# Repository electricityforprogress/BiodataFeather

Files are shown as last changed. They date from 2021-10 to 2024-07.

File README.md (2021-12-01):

# BiodataFeather
Feather daughter board for the Adafruit ESP32 and Huzzah (and others), allowing BLE and RTPMIDI via wifi.
Still a work in progress, and can provide the framework for anyone to use other Adafruit Feather boards
     Lots of Biodata information on my website electricityforprogress.com
See also the project submission on [Hackaday.io](https://hackaday.io/project/182849-biodata-sonification-v05)

3D Enclosure Model: https://www.tinkercad.com/things/8HZnh0ERNtr-biodata-wifi-snap-enclosure

Menu Modes:

From normal Biodata mode, by pressing the button you will enter into the Menu selection where you can turn the knob to select different menus listed below.  When the desired menu color is illuminated click the button and continue to turn the knob to choose a value.  Click a final time to select the value and return to Biodata Mode.  Selections are saved and reloaded each time you turn on the device.  To 'hard reset' press and hold the button while turning on the device, after the light show the White led will display and the factory default settings are applied (Chromatic Scaling, Channel 1, Bluetooth ON, Wifi OFF).

Red - Note Scaling - Entering this mode will illuminate the Red LED, by turning the knob one of the other LEDs will flash indicating a different Note Scaling. Flashing Red = Chromatic, Orange = Minor, Green = Diatonic Minor, Blue = Major, White = Indian

Orange - MIDI Channel - Entering this mode will illuminate the Orange LED, by turning the knob different combinations of the LEDs are used to display the MIDI Channel in 'Binary'.  MIDI Channel can be configured between 1-16, each of the 5 LEDs are used to display the MIDI channel chosen where 1 = 1xxxx, 2 = x1xxx, 3 = 11xxx, etc. The MIDI Channel can then be saved by pressing the button.  So far, this MIDI selection method has been a big PiTA for users, but it is kinda clever.

Green - Wifi On/Off - This mode turns on and off Wifi, default is off. Control is similar to the Bluetooth mode.  If you have uploaded code with your wifi credentials, you can connect to WiFi MIDI

Blue - Bluetooth On/Off - This mode turns on and off Bluetooth, default is ON.  The Blue LED will illuminate and either the Red LED (indicating off) or White LED (indicating on) can be selected by turning the knob.  Press the button again to save the setting.

White - Battery Level - Entering into this mode will display the battery charge percentage by illuminating the white LED and one of the other colors will flash.  Flashing blue = 100%, green = 80%, Yellow = 50%, Green = 30%

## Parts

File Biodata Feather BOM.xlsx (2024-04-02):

Index | Manufacturer Part Number | Manufacturer Name | Description | Attrition % | Requested Quantity 1 | Pack Quantity 1 | Pack Type 1 | Digi-Key Part Number 1 | Unit Price 1 | Extended Price 1 | Minimum Order Quantity 1 | Image | Product Notes
1 | 1825910-7 | TE Connectivity ALCOSWITCH Switches | SWITCH TACTILE SPST-NO 0.05A 24V |  | 1 | 1 | Bulk | 450-1804-ND | 0.13000 | $0.13 | 1 | http://mm.digikey.com/Volume0/opasdata/d220001/medias/images/609/1825910-7.JPG
2 | FG18X7R1H472KNT06 | TDK Corporation | CAP CER 4700PF 50V X7R RADIAL |  | 1 | 1 | Cut Tape (CT) | 445-173274-1-ND | 0.27000 | $0.27 | 1 | https://mm.digikey.com/Volume0/opasdata/d220001/medias/images/1206/FG18_Type.jpg
3 | CFM14JT10R0 | Stackpole Electronics Inc | RES 10 OHM 5% 1/4W AXIAL |  | 7 | 7 | Cut Tape (CT) | S10QCT-ND | 0.10000 | $0.70 | 1 | http://mm.digikey.com/Volume0/opasdata/d220001/medias/images/2453/CFMSeries 10.jpg
4 | CFM14JT3K90 | Stackpole Electronics Inc | RES 3.9K OHM 5% 1/4W AXIAL |  | 1 | 1 | Cut Tape (CT) | S3.9KQCT-ND | 0.10000 | $0.10 | 1 | http://mm.digikey.com/Volume0/opasdata/d220001/medias/images/2385/CFMSeries 3-9k.jpg
5 | SJ1-3525NG-GR | CUI Devices | CONN JACK STEREO 3.5MM R/A |  | 1 | 1 | Tray | CP1-3525NG-GR-ND | 0.73000 | $0.73 | 1 | https://mm.digikey.com/Volume0/opasdata/d220001/medias/images/378/MFG_SJ1-3525NG-GR.jpg
6 | CME0303S3C | Murata Power Solutions Inc. | DC DC CONVERTER 3.3V 750MW |  | 1 | 1 | Tube | 811-2889-5-ND | 3.25000 | $3.25 | 1 | https://mm.digikey.com/Volume0/opasdata/d220001/medias/images/2699/MFG_cmes3c.jpg
7 | 3405 | Adafruit Industries LLC | HUZZAH32 ESP32 FEATHER LOOSE HDR |  | 1 | 1 | Bulk | 1528-2181-ND | 19.95000 | $19.95 | 1 | http://mm.digikey.com/Volume0/opasdata/d220001/medias/images/2232/MFG_3405.jpg
8 | 2011 | Adafruit Industries LLC | BATTERY LITH-ION 3.7V 2AH |  | 1 | 1 | Bulk | 1528-1857-ND | 12.50000 | $12.50 | 1 | http://mm.digikey.com/Volume0/opasdata/d220001/medias/images/4848/MFG_1528_2011.jpg
9 | LMC555CN/NOPB | Texas Instruments | IC OSC SINGLE TIMER 3MHZ 8-DIP |  | 1 | 1 | Tube | LMC555CN/NOPB-ND | 1.53000 | $1.53 | 1 | https://mm.digikey.com/Volume0/opasdata/d220001/medias/images/376/8-DIP.jpg
10 | SJ1-3525NG | CUI Devices | CONN JACK STEREO 3.5MM R/A |  | 1 | 1 | Tray | CP1-3525NG-ND | 0.99000 | $0.99 | 1 | https://mm.digikey.com/Volume0/opasdata/d220001/medias/images/1172/SJ1-3525NG.jpg
11 | 1825232-1 | TE Connectivity ALCOSWITCH Switches | SWITCH SLIDE SPDT 200MA 30V |  | 1 | 1 | Bulk | A107673-ND | 0.46000 | $0.46 | 1 | http://mm.digikey.com/Volume0/opasdata/d220001/medias/images/665/1825232-1.JPG
12 | LTV-816 | Lite-On Inc. | OPTOISOLATR 5KV TRANSISTOR 4-DIP |  | 1 | 1 | Tube | 160-1360-5-ND | 0.39000 | $0.39 | 1 | https://mm.digikey.com/Volume0/opasdata/d220001/medias/images/371/ZJY51R5-2PB-01.jpg
13 | PTV09A-4015U-B103 | Bourns Inc. | POT 10K OHM 1/20W CARBON LINEAR |  | 1 | 1 | Tray | PTV09A-4015U-B103-ND | 1.02000 | $1.02 | 1 | http://mm.digikey.com/Volume0/opasdata/d220001/medias/images/13/PTV09A-4015U-B103.JPG
14 | FIT0096 | DFRobot | BREADBRD TERM STRIP 3.20X2.00" |  | 1 | 1 | Bulk | 1738-1326-ND | 2.90000 | $2.90 | 1 | http://mm.digikey.com/Volume0/opasdata/d220001/medias/images/833/FIT0096.jpg
15 | INL-3AY30 | Inolux | LED YELLOW CLEAR 3MM T/H |  | 1 | 1 | Bag | 1830-1002-ND | 0.36000 | $0.36 | 1 | https://mm.digikey.com/Volume0/opasdata/d220001/medias/images/729/INL-3AB30.JPG
16 | INL-3AR30 | Inolux | LED RED CLEAR 3MM T/H |  | 1 | 1 | Bag | 1830-1000-ND | 0.36000 | $0.36 | 1 | https://mm.digikey.com/Volume0/opasdata/d220001/medias/images/729/INL-3AB30.JPG
17 | INL-3AW30 | Inolux | LED WHITE CLEAR 3MM T/H |  | 1 | 1 | Bag | 1830-1006-ND | 0.40000 | $0.40 | 1 | https://mm.digikey.com/Volume0/opasdata/d220001/medias/images/729/INL-3AB30.JPG
18 | INL-3AB30 | Inolux | LED BLUE CLEAR 3MM T/H |  | 1 | 1 | Bag | 1830-1005-ND | 0.35000 | $0.35 | 1 | https://mm.digikey.com/Volume0/opasdata/d220001/medias/images/729/INL-3AB30.JPG
19 | INL-3AYG30 | Inolux | LED YLW-GRN CLEAR 3MM T/H |  | 1 | 1 | Bag | 1830-1003-ND | 0.36000 | $0.36 | 1 | https://mm.digikey.com/Volume0/opasdata/d220001/medias/images/729/INL-3AB30.JPG
20 | 5323 | Adafruit Industries LLC | ESP32-S3 FEATHER 8MB/0MB PSRAM |  | 1 | 1 | Bulk | 1528-5323-ND | 17.50000 | $17.50 | 1 | https://mm.digikey.com/Volume0/opasdata/d220001/medias/images/4845/MFG_1528_5323.jpg

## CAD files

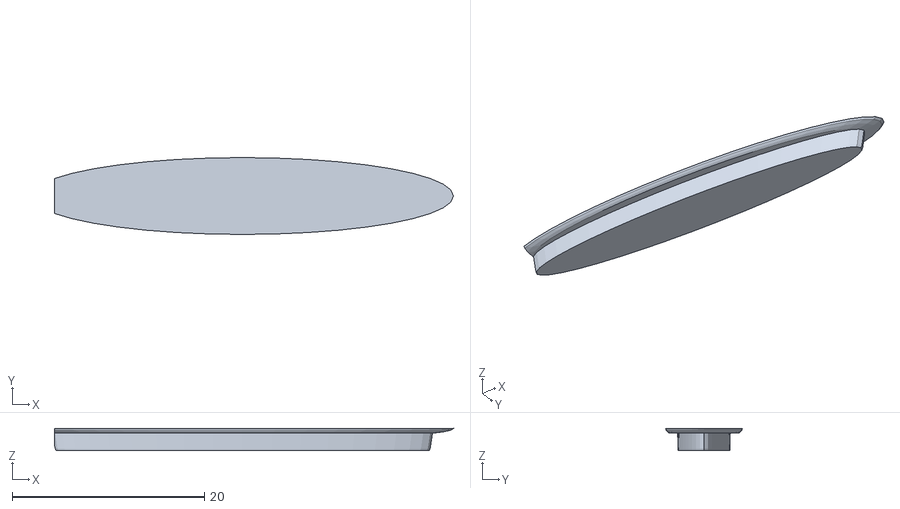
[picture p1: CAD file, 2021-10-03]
Biodata_Feather_ESP32Wifi_04/BiodataLEDdiffuser.stl
41.5 x 7.99 x 2.30

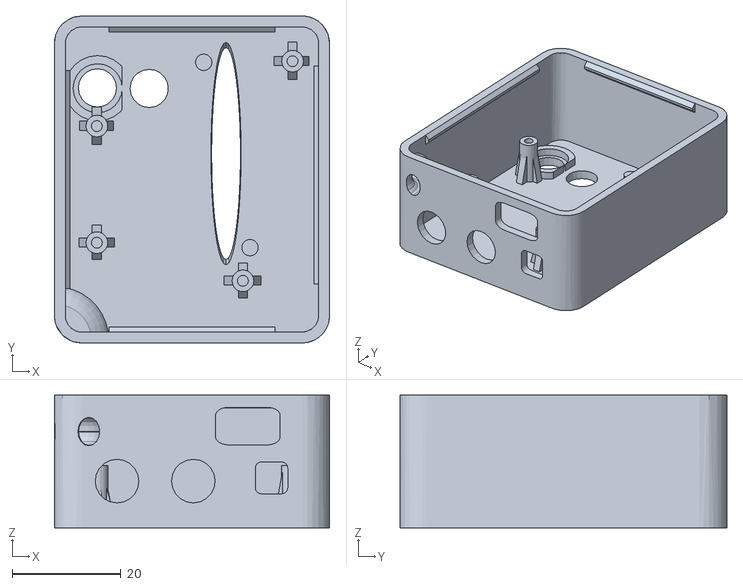
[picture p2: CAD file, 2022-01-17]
BiodataEnclosure/BiodataShortie_top_001.stl
50.5 x 60.0 x 24.4

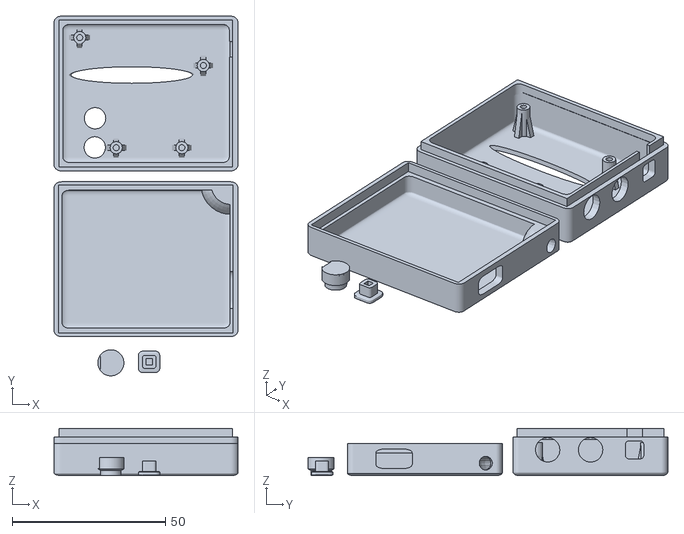
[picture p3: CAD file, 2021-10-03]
Biodata_Feather_ESP32Wifi_04/Biodata Wifi Enclosure Shortie.stl
60.0 x 117.3 x 15.4

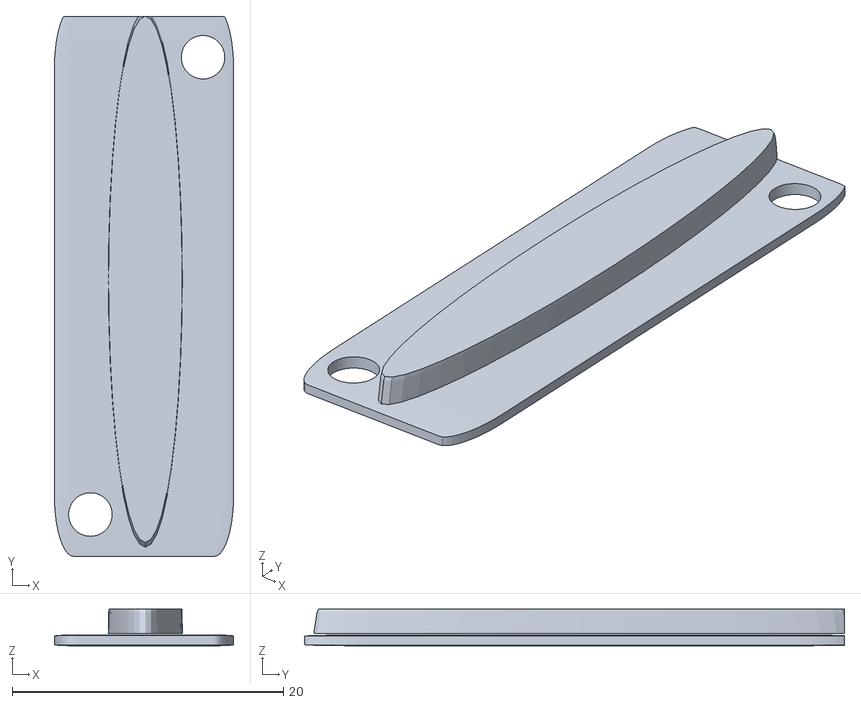
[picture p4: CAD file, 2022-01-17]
BiodataEnclosure/BiodataDiffuser_001.stl
13.2 x 39.8 x 2.70

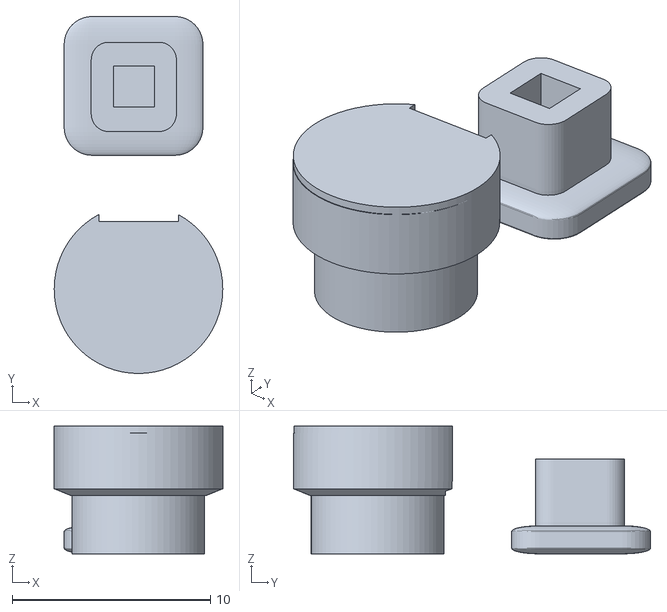
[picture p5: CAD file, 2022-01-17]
BiodataEnclosure/BiodataButtons_001.stl
8.50 x 18.0 x 6.44

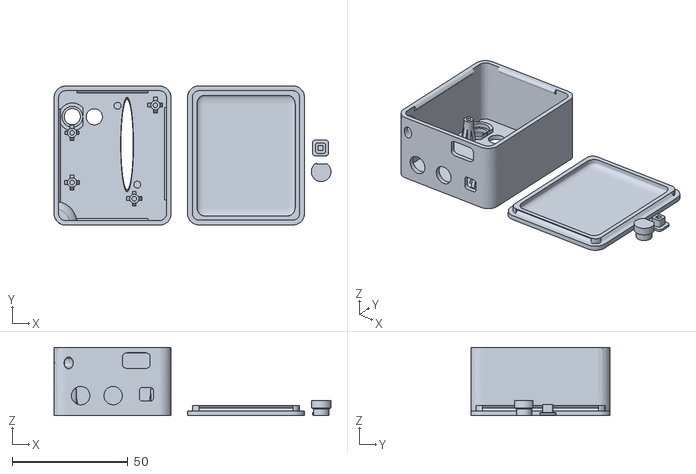
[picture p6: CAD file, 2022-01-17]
BiodataEnclosure/BiodataSnapEnclosure_set_001.stl
119.4 x 60.1 x 29.4

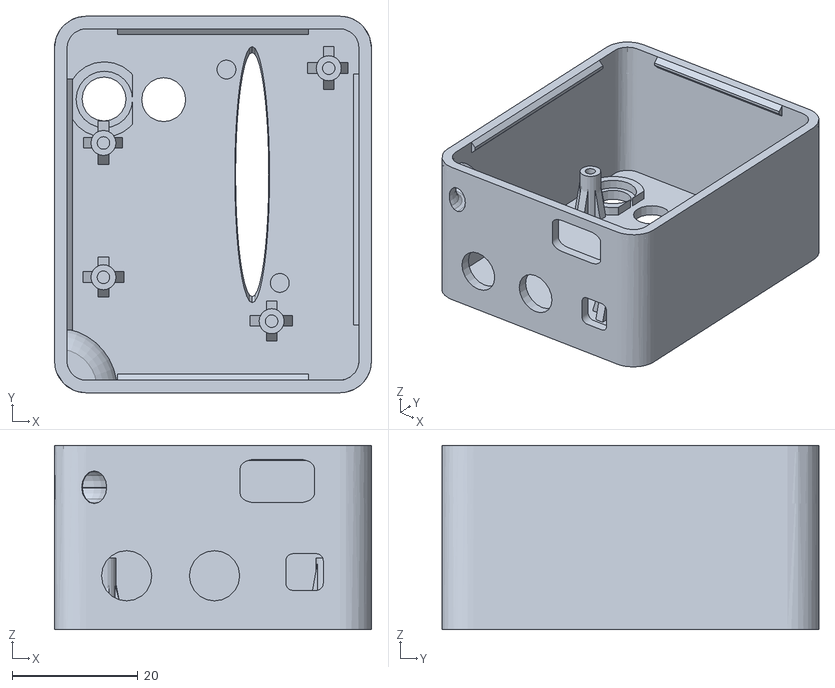
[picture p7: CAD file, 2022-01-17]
BiodataEnclosure/BiodataSnapEnclosure_top_001.stl
50.5 x 60.0 x 29.4

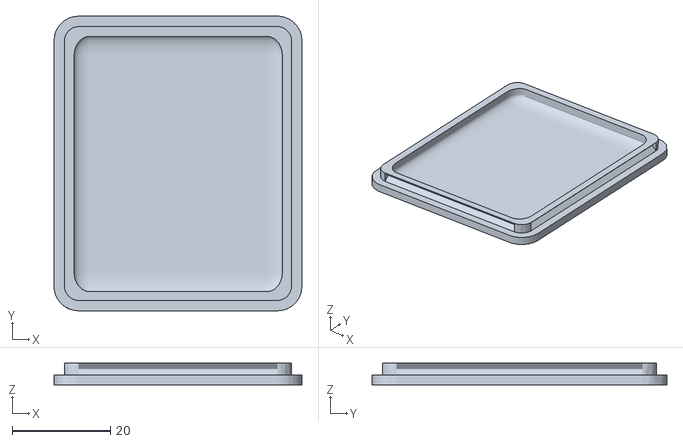
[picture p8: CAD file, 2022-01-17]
BiodataEnclosure/BiodataSnapEnclosure_bottom_001.stl
50.5 x 60.0 x 4.40

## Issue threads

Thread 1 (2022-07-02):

Update on ESP32-S3: compiled!

ooktown, 2022-07-02:
Hi Sam - I wanted to give you an update on my progress with the BiodataFeather code.

**The good news:** I've compiled the code for the ESP32-S3 chip, and uploaded it successfully!
**More good news:** When I first plugged the ESP32-S3 into my Mac, it was immediately recognized as a "keyboard" (native USB works!).
**Even more good news:** I can connect to the board via BLE.

**The bad news:** It's not connecting to the network. Here's the error it's giving:

`[WiFiUdp.cpp:219] parsePacket(): could not receive data: 9`

I'll be digging into it to see if I can get it to connect to the WiFi successfully. I'm also going to try adding the WiFi Manager code so I can let other people use the interface on their network.

electricityforprogress, 2022-07-02:
Oh yeah, wifimanager is a great option.  I've been 'rolling my own' AP with wifi credentials, but don't have anything running well enough to share as of yet.

ooktown, 2022-07-02:
FYI, here are the stats from compiling the code for the [ProS3](https://esp32s3.com/pros3.html) (ESP32-S3) from Unexpected Maker:

```
Retrieving maximum program size .pio/build/um_pros3/firmware.elf
Checking size .pio/build/um_pros3/firmware.elf
Advanced Memory Usage is available via "PlatformIO Home > Project Inspect"
RAM:   [==        ]  20.7% (used 67828 bytes from 327680 bytes)
Flash: [==        ]  18.7% (used 1224517 bytes from 6553600 bytes)
Building .pio/build/um_pros3/firmware.bin
esptool.py v3.3
Creating esp32s3 image...
Merged 2 ELF sections
Successfully created esp32s3 image.
```
I'm not sure how that will translate for the Adafruit ESP32-S3 Feather which has only 4MB Flash and 2MB PSRAM.

I also compiled a WebServer Portal as a Proof-of-Concept created by [Khoi Hoang](https://github.com/khoih-prog/ESPAsync_WiFiManager), and it worked with no problems. Next challenge is to integrate the code into the BiodataFeather code base. And then cross my fingers it fits into the Adafruit ESP32-S3 Feather flash! :-D

I'd be glad to share my code once I get it up and running.

electricityforprogress, 2022-07-04:
This is all really great thank you so much for putting in the legwork to get the wifi server running!  I have a couple other newer versions of the code with minor variations and features.  If you continue to modify the V005 code then I can merge stuff together.  Please share your codebase

I had setup the 'samFader' objects to use the ESP32 channels, but it is more of a hack.

As you have seen, my Menu routine is absolutely horrible, this is something which I will also have refinements for.

There are a couple of places where the serial, bluetooth, and wifi MIDI notes and CC controls are set and updated, it should be easy to include a block of code for the USB MIDI and pop in a MIDI flush.

I'll spin up a biodata board with the Adafruit ESP32-S3 and look at the fading leds.

ooktown, 2022-07-04:
Here ya go! I'm not a coder by trade. Just a hacker... I hope I put enough comments in there to guide you through my changes.

Theoretically, this code should compile and run on the ESP32 feather you have, so you can try it out right away:

Since you're make tweaks to the code, I'll wait to pull down an updated version from Github if you can get the WiFi manager running on the ESP32 Feather.

Let me know if you want my help!

Take care,

Stuart Yoshida

Ukulele Instructor and Performer
"A Seriously Fun Place of Learning"
www.ooktown.com <http://www.ooktown.com/>
***@***.*** ***@***.***>
Podcast: www.ooktown.com/podcasts

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

ooktown, 2022-07-04:
Made some corrections to add back in your LED code:

Stuart Yoshida

Ukulele Instructor and Performer
"A Seriously Fun Place of Learning"
www.ooktown.com <http://www.ooktown.com/>
***@***.*** ***@***.***>
Podcast: www.ooktown.com/podcasts

Closed 2022-07-04.

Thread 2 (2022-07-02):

BiodataFeather board question: substitute for 3.9K timer resistor? Also, NE555 vs LM555 chip tradeoffs?

ooktown, 2022-07-02:
Hi Sam - I had a question on a resistor value for the LM555 timer chip: what can I substitute for the 3.9K resistor? I have 3.3K or 4.7K resistors, but unfortunately I don't have any 3.9K resistors. Can I substitute one of those values for the 3.9K?

Also, I'm ordering some LMC555CN timer chips, but I have lots of NE555 chips. I was planning on temporarily using the NE555 timer chip in the socket while I wait for the LMC555CN chips.

What are the drawbacks for using the NE555 chip? I read that the NE555 chip is less stable over temperature and time. Will this cause glitching in the biodata?

Thanks again for all the great work on the BiodataFeather! It's awesome to have this as an open-source project.

electricityforprogress, 2022-07-02:
The Biodata device uses a 555 timer to detect electrical conductivity between two probes.  The Resistor and Capacitor network set the 'rate' at which the 555 timer detects changes.  You can substitute a similar value resistor without huge impact to the detection.

When it comes to 555 timers not all are built the same!  The important thing with this circuit is that we use a 'low power' timer which will operate at the 3.3v of the ESP32.  This leaves VERY FEW options, and the LMC555 is the primary timer which does all of the magic.  Now I already know there are no through-hole LMC555 timers available anywhere in the world, and many chips which are out there are 'fake', the chip crisis is looming.

I always say "experimentation is proof", you can pop a timer in and try it out, but sadly the NE555 needs 5v by the spec sheet.  From a circuitry standpoint, you very well might be able to get a 5v 555 timer running through an optoisolator and send that signal into the ESP32.  There are so soo soooo many 555 timer chips, and many low voltage models.... I have only found that the LMC555 does the magic best, but you are welcome to try other timers and share your results!

One other part of the circuit is a DC-DC voltage isolator, this is very important if you are connecting to USB.  We want to 'galvanically isolate' the 555 timer from any ground or certainly from your Laptop power supply.  Also if your audio output on the laptop is connected to a stereo system ... this creates a Ground Loop.  Be aware that this will happen, your circuit may work just fine but if you can properly isolate the detection circuit then you will get maximum sensitivity.  All of this is why I use Bluetooth and rechargeable batteries!

ooktown, 2022-07-02:
Thanks for all the feedback, Sam!

I'll substitute a 4.7k resistor for the 3.9k.

I have some supposed LM555 timer on order, but they may very well may be fakes. We'll see how it operates when I stick one in the circuit.

I will definitely keep the isolator in the design to make the input as clean as possible.

And I also prefer using BLE with batteries!

ooktown, 2022-07-04:
Once I get some parts together, I'll will try out some 555 chips in the socket to see what works. For now, I'll close this issue.

Closed 2022-07-04.

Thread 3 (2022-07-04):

Which pins are beings use for Serial1?

ooktown, 2022-07-04:
Latest update: I have the captive portal working for WiFi for general configuration.

I think I've run into a limitation with the current ESP32-S3 SDK, because using the Serial1 port seems to crash. There might be a workaround if I explicitly define the Serial1 pins. Which pins on the Feather are you using so I can try out this workaround?

electricityforprogress, 2022-07-04:
It is mapped to IO17 for tx on the adafruit feather

ooktown, 2022-07-04:
Thanks! I'll give that a try.

electricityforprogress, 2022-07-04:
You could also just hack out all the hardware serial code if it's causing a compile issue for the s3. Unless you intend to use hardware serial rather USB.  I'll politely apologize for my extremely messy menu coding. But hey that's just how it rolls... I'll refactor this later ... as the saying goes

ooktown, 2022-07-04:
Ok, found the issue: the LED fader routine in the setup() is causing the crash. I took it out, and the code is running!

So we can close this issue.

WiFi captive portal: working (tested, can connect to WiFi from portal)
BLE: working (untested, but showing up on Bluetooth sniffer and I can connect)
Serial1: working (untested, but it's not crashing :-) )

While I wait for the parts for the galvanic interface to arrive, I'll work on debugging the LED fader function and try to get MIDI over USB working.

And no worries about the nested menu code. I just "prettified" it by formatting it enough so I could grok what was going on. :-D

Closed 2022-07-04.

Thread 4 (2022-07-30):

Optoisolator alternative?

inktrap, 2022-07-30:
This Optoisolator:

```
CNC1S171S0LF	Panasonic Electronic Components	OPTOISOLATOR 5KV TRANSISTOR 4DIP
```

seems to be obsolete and not manufactured anymore:
https://www.digikey.de/en/products/detail/panasonic-electronic-components/CNC1S101/970631
However I found the **R0** instead of the **S0**:
https://www.digchip.com/datasheets/parts/datasheet/2099/CNC1S171R0LF.php

The specs seem to be the same: https://www.findchips.com/parametric/Optoelectronics/Optocoupler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*

inktrap, 2022-07-30:
Also the pc 817 is all over the place … and seems fitting … https://www.findchips.com/parametric/Optoelectronics/Optocoupler?term=pc817&Manufacturer%20Part%20Number=pc817

ooktown, 2022-07-30:
We have successfully used the [LITEON LTV-816](https://www.digikey.com/en/products/detail/liteon/LTV-816/385830?s=N4IgTCBcDaIIwDYAMBaOBmZKCsKByAIiALoC%2BQA) on a batch of four Biodata boards as an alternative part. YMMV.

The boards are for a music project I'm collaborating on, and all four boards using the LITEON optoisolator are operational.

electricityforprogress, 2022-07-31:
Excellent! I just got home from a beach weekend and I'm super glad to hear
that you have everything up and running. Yeah most of the isolators with 3v
operating voltage will work with this module. Most of the parts are pretty
generic really only thing that is important is the 555 timer it seems. I
have tried using many alternatives and other low power timers and the LTC
555 from Texas instruments is alway the best choice for me.

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

inktrap, 2022-08-03:
Hey :) thank you for your answers! It took some doing but i finally ordered all the components, and I double checked that I have the right ones. I gues 20AWG wire would be sufficient? Also I just hope that the pcb will work, but that is an experiment. First time ordering a PCB :D I guess I will build this on a breadboard first to get a feeling for it, then on one of the PCBs.

electricityforprogress, 2022-08-03:
Yes really any wire will work for the electrode leads, it is easy enough to
recycle some headphone cables or use some flexible two conductor.  The
commercial wires on headphones and electrodes are probably way thinner than
20 awg.

What are your concerns about the PCB?  If you used my gerber files and sent
to a board manufacturer then yeah everything should work easily.  I use
NextPCB, but most people see the PCBway adverts or JLCpcb ... if this is
your 'first time customer' at a PCB house and you only are buying 5 of one
design, the boards should be 'free' and just pay shipping ...

Yes yes yes, definitely build on breadboard first to make sure you have all
the right parts and values ;) also make sure to use a socket for your 555
timer ... if you have a problem in assembly at least the 555 timer is easy
to salvage!  But if you watch my soldering and assembly videos the process
should be simple for you.

Sam Cusumano
Electricity for Progress <https://squareup.com/store/electricityforprogress>
***@***.***
267-230-1802

On Wed, Aug 3, 2022 at 3:05 AM Valentin Heinz ***@***.***>
wrote:

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

inktrap, 2022-08-03:
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

Ah, I bought some electrode leads and some 20AWG wire for another
project but won't be needing it because everything is directly soldered
to the board. Next time I am going to recycle something and build my
own. I think I should be able to do this with the video tutorial … that
was very well explained, so thanks for that! :)

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

Oh I got some 2-3€ discount and paid like 2€ for the pcbs and 5€ for
shipping and I chose black as the pcb color which increased the price a
bit. Also they have to pay import taxes that they will price in.

I didn't use your gerber files, just the once I exported from eagle.
Since I have never done this before, it was exciting, and that is where
my concerns come from … there is no explicit reason that I know of why
this could go wrong. Maybe it's like flying for the first time?

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

Yes, I read the tips and also the forum and ordered some sockets.
Since this is my first project I have to learn how/where I can salvage
things … as of now I am just happy that I bought the right parts ;P

Thanks, again! :)

ooktown, 2022-08-03:
I will second the advice of having the 555 timer in a socket. It allowed us to try different chips and will make replacement easy, if needed.

Also, before having the parts soldered to the PCB, I randomly ohm'd out about five traces to give me confidence the board was manufactured correctly.

Good luck! It's a fun project.

inktrap, 2022-08-03:
Which timers did you try, different versions of the 555 or completly different timers, and what were the effects? I recently found out that there are also adjustable timers, that give some more flexibility, something like this: https://duckduckgo.com/?q=arduino+adjustable+555+chip&t=ffab&iar=images&iax=images&ia=images

And yes, I chose this project because it is fun and also beginner friendly, very well documented and it also helps that I love music, plants, and the creative and educational aspects, so … awesomeness all around ;P Another awesome project that I wanted to mention is the pedalpiv2 that could be used during a live-performance that could accompany the daw with biosonic music … https://github.com/thawney/PedalPiV2

electricityforprogress, 2022-08-04:
When the 'chip shortage' was first talked about, I tried a couple different alternative low voltage timer on a simple breadboard circuit with an ESP32 Feather.  The results were surprising ...
1. TS555CN https://www.amazon.com/gp/product/B07FJ6Y3VR/ref=ppx_yo_dt_b_search_asin_title?ie=UTF8&psc=1
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
electricityforprogress, 2022-08-04:
For an Adjustable timer I really have no idea, i mean the 555 is an adjustable timer and the LMC is just the cmos low power version.  I think that the device is using a minor 'trick' pushing pulse widths based on microcurrent changes across the threshold and discharge pins.

I had entertained the idea of doing some more 'monetized' content on youtube, but then i realized that other organizations can simply claim the monetization due to strange audio algorithms.... and so honestly fu** that right in the goat a** , I'd rather not do the whole 'ask youtube and sponsors to pay for the content based on ad revenue and copyright hunters.  what grotesque economy!   (grumble....as i pay my $10 monthly youtube-red account to avoid ads)

great comments, cheers!

inktrap, 2022-08-04:
> For an Adjustable timer I really have no idea, i mean the 555 is an adjustable timer and the LMC is just the cmos low power version.  I think that the device is using a minor 'trick' pushing pulse widths based on microcurrent changes across the threshold and discharge pins.
>

Ah I had no idea what the timer does … ofc. it sends pulses for measuring, I read up on that, but since I am brand new to electronics I assumed it was somehow fixed. I still have to learn a lot … and I guess I will turn to youtube for that …

> I had entertained the idea of doing some more 'monetized' content on youtube, but then i realized that other organizations can simply claim the monetization due to strange audio algorithms.... and so honestly fu** that right in the goat a** , I'd rather not do the whole 'ask youtube and sponsors to pay for the content based on ad revenue and copyright hunters.  what grotesque economy!

I mean the question is if you like the idea to be someone who does more monetized or streamlined content. I guess people who do that like doing it despite youtube's "stance" on content. With more professionalization (as in profession) stuff becomes somewhat interchangeable too, and the artsy-video I linked is much more authentic/fascinating, at least to me. I don't want to put content creators down when I write that, those two types of videos are simply so different that the videos are two different things.

> (grumble....as i pay my $10 monthly youtube-red account to avoid ads)
>

May I interest you in https://ublockorigin.com/ and https://github.com/ytdl-org/youtube-dl then?
And if you can install f-droid on android https://github.com/TeamNewPipe/NewPipe/ is awesome-sauce :)
A good network-based solution is https://pi-hole.net/

> great comments, cheers!

thanks :)

ooktown, 2022-08-05:
> Which timers did you try, different versions of the 555 or completly different timers, and what were the effects? I recently found out that there are also adjustable timers, that give some more flexibility, something like this: https://duckduckgo.com/?q=arduino+adjustable+555+chip&t=ffab&iar=images&iax=images&ia=images And yes, I chose this project because it is fun and also beginner friendly, very well documented and it also helps that I love music, plants, and the creative and educational aspects, so … awesomeness all around ;P Another awesome project that I wanted to mention is the pedalpiv2 that could be used during a live-performance that could accompany the daw with biosonic music … https://github.com/thawney/PedalPiV2

We used some LMC555CN knock-off parts. It was a gamble that paid off. YMMV. Authentic TI parts, as Sam has mentioned, are hard to come by. This chip shortage really sucks!

inktrap, 2022-08-05:
> We used some LMC555CN knock-off parts. It was a gamble that paid off. YMMV.

I ordered some LMC555CN timers via aliexpress and can provide feedback wether that worked for me too. I am optimistic ;P. Side note: I asked about ROHS compliance and they had no idea about that because "they are just as distributor". Do I have to worrry about ROHS? At least I made sure that the PCB is ROHS+lead-free.

Also about the chip-shortage: I mentioned pedal-pi earlier which requires an raspberry pi zero … and you can only buy them used and for around 6 times the original value. Maybe, if it is still a hobby, the solution is to do less and to be happy with less? I will wait with my pedal-pi build :).

ooktown, 2022-10-11:
FYI: I used the ECAD module in Fusion 360 to successfully open the design files and export Gerber files for manufacturing at a vendor.

And I also love having colorful boards! We have so far printed purple and white boards. Both colors look great!

inktrap, 2022-10-11:
When I'll finish it (and it hopefully works) I'll send you a picture of
the black one :D

Closed 2022-10-01.

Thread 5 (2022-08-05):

Request: code to enable double-click, long-click on buttons

ooktown, 2022-08-05:
I'm looking to add the ability to enable and disable some additional options for the Biodata Feather interface (extra CC messages, AP setup), and it would be great to turn on/off these options with a double-click or long-click.

It appears that the samButton class was partially set up to support these functions, but I don't think it was fully enabled. Would you post the additions/updated samButton class to add these abilities?

electricityforprogress, 2022-08-05:
Hmm, perhaps ;) but unlikely in any relative timeframe.  I only spun my own for portability.  Thinking about it, this should be trivial to implement.  If i can think of something (or you can suggest something) for which long press would be valuable then i might do it while watching Critical Role tonight.

Now i know that my menu code is totally the pits.  Describe how you want the AP to work, cause i have a couple ideas too.  I think it could be done in the wifi sub menu as a third option. ...  but i digress.

Give me one good reason to add long press and I'll do it ;)  - Cheers!

ooktown, 2022-08-05:
How about TWO reasons :-)

1. Turn on/off CC 84 for extra control over MIDI sounds. Once we get it going, we'll share what we're doing. For now we want to keep it under wraps ;-). Suffice to say, it should be very cool when we get it working with CC 80. This could be an option when in MIDI channel mode. FYI: I already have CC 84 working along side CC 80. I'm using a third-degree polynomial equation to give CC 84 more "wiggle" relative to CC 80.

1. Turn on/off WiFi STA mode. I am currently using the WiFi option to enable the AP mode to configure parameters, including the MIDI channel. (We will be adding more parameters as needed.) The AP eventually goes away for security purposes. I would like to be able to enable/disable WiFi connectivity to a network (STA mode) on-demand from the "Green" mode for future use with MQTT or to control LEDs by sending data to a [Pixelblaze](https://www.bhencke.com/pixelblaze), for example.

And double-click would work just as well as long-click, as far as I'm concerned.

ooktown, 2022-08-05:
And one more reason...

3. Set the sensitivity to be static at whatever setting the pot is at, and then use the pot to control a MIDI parameter.

Closed 2022-10-01.

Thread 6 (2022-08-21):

I ordered an ESP 8266 by mistake, do I need the Mhz?

inktrap, 2022-08-21:
I read that [the main difference is Mhz](https://www.utmel.com/components/esp32-vs-esp8266-which-is-better?id=921):

> The ESP32 is a dual-core 160MHz to 240MHz CPU, whereas the ESP8266 is a single-core processor that runs at 80MHz.The ESP32 and ESP8266 are both fantastic Wi-Fi modules.

Should I just by an [ESP32 from china](https://www.aliexpress.com/item/1005001757645011.html?mp=1) and send the [Feather ESP8266](https://www.reichelt.de/adafruit-feather-huzzah-ada-fb-huzzah-p235448.html) back?

electricityforprogress, 2022-08-21:
Sadly no the 8266 is an earlier version and has many fewer capabilities. We
use Bluetooth on the ESP 32. The 8266 can certainly run the code and could
output cereal data, and could probably even handle Wi-Fi RTP MIDI. But I do
not have a code base tested for that module and I'm sure there will be many
tweaks required.

I recommend trying to get an ESP 32s3 development board which does
everything the older esp32 does plus has USB midi. I have a new code base
for the ESP 32s3 on my GitHub.

On Sun, Aug 21, 2022, 3:37 PM Valentin Heinz ***@***.***>
wrote:

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

inktrap, 2022-08-21:
Ah alright, I am trying to return it then! What does the s3 stand for? [Would one of these work?](https://www.aliexpress.com/item/1005001757645011.html?mp=1) … They are also much cheaper …

electricityforprogress, 2022-08-21:
At $0.96 I would be very skeptical of that specific board. I really don't
know how best to advise you here, any esp32 dev board should work, you just
have to hook it all up right.

The S3 is a new model of the ESP 32.

You pretty much have to figure it out from this point though I'm not going
to map the pins and answer a whole bunch of questions about weird boards if
you know what I mean, no offense my friend.

On Sun, Aug 21, 2022, 4:07 PM Valentin Heinz ***@***.***>
wrote:

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

inktrap, 2022-08-22:
Hey :)

my apologies if that was an annoying question. I thought it would have an easy yes/no answer but it is much more complicated, which I understand now.

However, this level of complication leads to  … a let's say steep learning curve. Many abbreviations, a lot of subtle differences, boards have variants that behave differently … so it is easy to make mistakes. This is my first project and I have all the other parts. It would be quite sad if I bought the wrong one again, I am sure others also appreciate it that I am asking for one more detail regarding the board: does flash/sram matter? The ones I found are from 14-18€, so they have a reasonable price:

 - ESP32-S3-WROOM-1-N8R2(8M Flash/2SRAM)
 - ESP32-S3-WROOM-1-N8R8(8M Flash/8SRAM)
 - ESP32-S3-WROOM-1-N16R8(16M Flash/8SRAM)

The distinction between [ESP32-S3-WROOM-1, ESP32-S3-WROOM-1U, ESP32-S3-WROOM-2](https://www.espressif.com/en/products/modules/esp-wroom-32#ESP32-S3) (+ mini variants) doesn't seem to matter and I would go with the `1`.

It would be really helpful, and good from an didactical perspective, if that could be included in the BOM or documentation?! If not … feel free to close this issue, then I would just buy the largest one. I am also fine with choosing another project to learn the basics, so no questions about pinouts.

Last but not least: I could get my money back for the 8266 and they don't even want the board back?! Wow!

Thank you for your time and attention :)

electricityforprogress, 2022-08-22:
Sorry i get a bit twitchy when it comes to using different Dev boards.  I
teach electronics and I encounter questions about using other boards all
the time from students, and each face the same challenges.  Migrating
between Dev boards is fairly easy for an experienced programmer, and can be
very confusing for a beginner.

You raise an important point here.  There are many variations of the ESP32
board, and each variation will require a specific board definition file in
Arduino and each will have different parameters for compilation.   The
simple BOM shows the Adafruit ESP32 Huzzah Feather (and the latest version
of the code uses Adafruit ESP32-S3-2MB https://www.adafruit.com/product/5477
), if you use this specific dev board then you can use the pin mappings and
the libraries and compilation have been tested.  For any other dev board
there could be small differences which could cause challenges in compiling
and using libraries.

This Biodata codebase is very small, simple, and can run on almost any
microprocessor (Arduino, ATtiny).  The ESP32 is 'way overkill' for our
simple Biodata application, large storage and memory expansion is not used
in any way.  You can potentially use any ESP32 variety but you will have to
figure out all the abbreviations, pin mappings, ensure the version has
expected functionality (for example the ESP32 S2 doesn't have Bluetooth),
and hope that the libraries (USB-MIDI, AppleMIDI) will be compatible.

You can use a dev board with any one of the S3 WROOM modules and will need
to download the right board definitions and configure for your module in
Arduino.

Sam Cusumano
Electricity for Progress <https://squareup.com/store/electricityforprogress>
***@***.***
267-230-1802

On Mon, Aug 22, 2022 at 11:03 AM Valentin Heinz ***@***.***>
wrote:

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

ooktown, 2022-08-22:
I will concur with Sam that using the board specified in the design will make programming and set up WAAAAY easier.

At the time we made our boards, the only Feather ESP with BLE and native USB was the [FeatherS3 by Unexpected Maker](https://esp32s3.com/feathers3.html). I had to figure out the new pin layout and re-map the differences (pretty much every pin had to change), and even at that the Adafruit MIDI over USB library was stubborn and would not compile 👎  . So in the end, I took out the MIDI over USB feature (until such time that the library becomes compatible with the FeatherS3 by Unexpected Maker).

To me, the MVP is having WiFi and BLE with a battery. Really handy! Using the Biodata interface next to the plant without MIDI or USB cabling is awesome.

electricityforprogress, 2022-08-23:
closed - send an email if you need more help!

Closed 2022-08-23.

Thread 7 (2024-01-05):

Values not changing or result not accurate

quintendewilde, 2024-01-05:
Hi

I'm hoping I get some response here even though the project is still not very much alive anymore.

But I'm making a simplified version of the project and stuck with the results being the same.

I'm using the breadboard example here. (I have all the parts for the PCB board too but, unable to recreate it with perfboard, my schematic reading isn't very good as I am no a very technical person)
[Breadboard example](https://electricityforprogress.com/biodata-breadboard-kit/)

This is my code

```
/*----------------------------------------------------------
   Everything for OSC && WiFi
  ----------------------------------------------------------*/

#if defined(ESP8266)
#include <ESP8266WiFi.h>        // Include the Wi-Fi library
#else
#include <WiFi.h>
#endif
#include <WiFiUdp.h>            // UDP library
#include <OSCMessage.h>         // OSC library
#include <OSCBundle.h>

#include <Wire.h>

WiFiUDP Udp; // A UDP instance to let us send and receive packets over UDP
//const IPAddress outIp(192, 168, 0, 234); // remote IP of your computer

const unsigned int outPort = 4560; // remote port to receive OSC
const unsigned int localPort = 8888; // local port to listen for OSC packets (actually not used for sending)

// Sensor and analysis setup
const int sensorPin = A0; // Wemos A0 gpio
const byte samplesize = 10;
volatile unsigned long samples[samplesize];
volatile byte SampleIndex = 0;
float threshold = 2.3; // Adjust as necessary

void setup()
{
    Serial.begin(115200);
    delay(10);
    Serial.println('\n');

    WiFi.begin(ssid, password);             // Connect to the network
    Serial.print("Connecting to ");
    Serial.print(ssid); Serial.println(" ...");

    int i = 0;
    while (WiFi.status() != WL_CONNECTED) { // Wait for the Wi-Fi to connect
    delay(1000);
    Serial.print(++i); Serial.print(' ');
    }
    Serial.println('\n');
    Serial.println("Connection established!");
    Serial.print("IP address:\t");
    Serial.println(WiFi.localIP());         // Send the IP address of the ESP8266 to the computer

    Serial.println("Starting UDP");
    Udp.begin(localPort);
    Serial.print("Local port: ");
    #ifdef ESP32
      Serial.println(localPort);
    #else
      //Serial.println(Udp.localPort());
    #endif

  // Sensor setup
  pinMode(sensorPin, INPUT);
  Serial.println("Setup complete");

}

/*----------------------------------------------------------
    Galvano sensor  loop
  ----------------------------------------------------------*/
void loop() {
  // If the samples array is full, analyze the sample
  if (SampleIndex >= samplesize) {
    analyzeSample();
  }

  // Read sensor data
  if (SampleIndex < samplesize) {
    samples[SampleIndex++] = analogRead(sensorPin);
    delay(5); // Delay between samples
  }
}

void analyzeSample() {
  unsigned long sum = 0;
  unsigned long maxVal = 0;
  unsigned long minVal = 4294967295; // Max unsigned long
  float stdDev = 0;

  for (byte i = 0; i < samplesize; i++) {
    sum += samples[i];
    if (samples[i] > maxVal) maxVal = samples[i];
    if (samples[i] < minVal) minVal = samples[i];
  }

  float avg = sum / (float)samplesize;
  for (byte i = 0; i < samplesize; i++) {
    stdDev += pow(samples[i] - avg, 2);
  }
  stdDev = sqrt(stdDev / samplesize);

if ((maxVal - minVal) > (stdDev * threshold)) {
    OSCMessage msg("/sensor/change");
    msg.add((float)avg); // Casting to float
    Serial.println(avg);
    msg.add((int)maxVal); // Casting to int
    Serial.println(maxVal);
    msg.add((int)minVal); // Casting to int
    Serial.println(minVal);
    msg.add((float)stdDev); // Casting to float
    sendOSCMessage(msg);
  }

  SampleIndex = 0; // Reset index for next samples
}

void sendOSCMessage(OSCMessage &msg) {
  Udp.beginPacket(outIp, outPort);
  msg.send(Udp); // Send the message
  Udp.endPacket();
  msg.empty(); // Free space occupied by the message
  Serial.println("OSC message sent");

}
```

Replaced every piece of the board incase something might be faulty (tried three different Wemos boards)
Quadrupple checked my wiring

This is the output of the serial monitor:

```
2 3 4

Connection established!
IP address:	192.168.0.114
Starting UDP
Local port: Setup complete
2.60
4
2
OSC message sent
0.80
2.50
4
2
OSC message sent
0.67
2.70
4
2
OSC message sent
0.78
2.70
4
2
OSC message sent
0.78
2.70
4
1
OSC message sent
1.00
2.70
4
2
OSC message sent
0.78
2.70
4
2
OSC message sent
0.78
2.90
3
2
OSC message sent
0.30
2.40
4
2
OSC message sent
0.66
2.50
4
2
OSC message sent
0.81
3.00
5
2
OSC message sent
0.89
2.50
3
1
OSC message sent
0.67
2.50
4
2
OSC message sent
0.67
2.60
4
2
OSC message sent
0.80
2.60
4
2
OSC message sent
0.66
2.60
4
2
OSC message sent
0.66
2.80
4
2
OSC message sent
0.75
2.80
3
2
OSC message sent
0.40
2.50
4
2
OSC message sent
0.81
2.50
4
2
OSC message sent
0.67
2.80
3
2
OSC message sent
0.40
2.50
4
2
OSC message sent
0.67
2.50
4
1
OSC message sent
0.92
2.70
5
2
OSC message sent
0.90
2.70
4
2
OSC message sent
0.78
2.60
4
2
OSC message sent
0.66
2.90
4
2
OSC message sent
0.70

```

This is what I get when I use the perfboard:

When I used my soldered version I get nothing..

@
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

electricityforprogress, 2024-01-05:
Hello and thank you for your interest in Biodata Sonification.  It sounds like you are trying to use the old breadboard kit instructions and use an ESP32.  Did you follow the breadboard instructions, does the 555 timer flash when the you touch the electrodes to test the biodata circuit?

... luckily i have a different codebase which will work on ESP32.  I recommend using an ESP32-S3 which has usb-midi as well as ble/wifi -- https://github.com/electricityforprogress/BiodataFeather/tree/master/Biodata_v007_ESP32S3

Looking briefly at your code, you don't seem to have the interrupt input declared in setup() or nor a function to perform the biodata reading.

quintendewilde, 2024-01-05:
Yes I followed the exact wiring.
And I used our ESP32 code to recreate my example.

I though I had it figured out correctly. But if u say that I don't have the interrupt input declared in setup or missing a function. Then I'm pretty sure I did that wrong :(. Hmm this goes beyond my programming knowledge as well.  I just want to send the variating data to osc and handle it from there...

electricityforprogress, 2024-01-05:
If you are trying a new project, i recommend getting it to work 'without changes' first and then go back and start to make your modifications, that will give you some ground to stand on while doing new work.  You can test to ensure your hardware is working.  Did you test the 555 circuit works with your fingers, that is step 0.

To use an 'arduino based' code project you need all of the .ino files in the project folder as well as any dependent libraries installed in the Arduino IDE.  So grab the entire repository and use the folder Biodata_v007_ESP32S3

I didn't go into your code deeply and there may be other issues, but this is how an interrupt works --

1. you need to declare the interrupt pin at the top of the code(in your case it is A0)
const byte interruptPin = A0; //galvanometer input

2. create the ISR function at the top of the code to read the pulse:
void sample(){
  if(sampleIndex < samplesize) {
    samples[sampleIndex] = micros() - microseconds;
    microseconds = samples[sampleIndex] + microseconds; //rebuild micros() value w/o recalling
    //micros() is very slow
    //try a higher precision counter
    //samples[index] = ((timer0_overflow_count << 8) + TCNT0) - microseconds;
    sampleIndex += 1;
  }
}

3. In Setup() you need to configure the pin and assign the ISR (interrupt routine):

  pinMode(interruptPin, INPUT_PULLUP); //pulse input
  //setup pulse input pin
  attachInterrupt(interruptPin, sample, RISING);  //begin sampling from interrupt
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
electricityforprogress, 2024-01-20:
I'm am excited that you are putting so much effort into this project and I want you to succeed.  But you must understand that I am sorry that i am not going to debug your personal version of the code, and certainly not some GPT based code (deep sadness from an educator).  From my review this morning, it looks like the code will run, and as you report your code does run but doesn't give you the results you want, so i dunno.

** You really should get the original code working first, and after that start to make your changes.  Load the original code based on your current build, you dont need the other LEDs if that's what you are avoiding.

1. Build the circuit per the instruction PDF
2. Ensure the 555 timer circuit is working before you try to connect to your arduino !!!!~! this is a step you are skipping
3. 'Add' blocks to the original code and try to get your desired outcomes

I think the only thing you need to do is take the original code, set 'rawSerial' = 1, upload and turn on the serial monitor to see the raw data values.

You need to find a local friend or Maker Arts Space where you can get direct assistance with your project.

just to be clear, this isn't an Issue with the codebase in github, rather this is a student question in an inappropriate forum.

Good luck with your project, try to rebuild it two or three more times (i'm serious) and you will get there

Issue CLOSED

electricityforprogress, 2024-01-20:
CLOSED

quintendewilde, 2024-01-20:
For the record, I did and still trying it on myself. I said I only used GPT to try to figure out what's wrong. Thanks for the advice though.

Closed 2024-01-20.

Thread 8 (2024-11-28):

Problems compiling with the latest version of Arduino 2.3.3

rafaelcortesUB, 2024-11-28:
I'm having trouble compiling your GitHub code with the latest version of Arduino. Do you know why?

Could you also add all the libraries required for the project to this repository?

Thank you.

Regards.

Rafael

electricityforprogress, 2024-11-28:
Oh that's too bad. You should be able to find all of the required libraries
in comments in the code. Perhaps it's an error with the ESP, I know the LED
initializers code has changed. I'm not really going to make any changes to
the repository anytime soon, but I'm sure you can figure it out.

On Thu, Nov 28, 2024, 11:17 AM RafaelCortesUB ***@***.***>
wrote:

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

Closed 2025-04-11.

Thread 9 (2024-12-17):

Problems with the code

rafaelcortesUB, 2024-12-17:
Hello, sorry, why this code not works like this:

https://www.youtube.com/watch?v=TpmWm8szL7c

Can you share with me the code of the video? please.

I have you board, but I don't know why not works like the video.

Regards.

Rafael

electricityforprogress, 2024-12-17:
You'll need to provide me with significantly more information in order for
me to be able to help you. What specific circuit board do you have, what
specific Arduino board do you have, do you have any experience programming
with Arduino, have you tested and uploaded known working code onto your
Arduino? You state that the code does not work, but what do you mean are
you unable to compile the code or have you compiled the code in certain
aspects of the device do not work as your expectations. Again you've
provided almost no meaningful information for me to be able to help you
here. My strongest recommendation is that you find either a local maker
arts space, or a friend who has experience with Arduino and work together
with someone who knows a bit more. Then this project can probably be fairly
easy. There are multiple versions of code up on GitHub each one is for a
slightly different board depending on what you specifically are using.

On Tue, Dec 17, 2024, 6:24 AM RafaelCortesUB ***@***.***>
wrote:

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

Closed 2025-04-11.

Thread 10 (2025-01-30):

Biodata_v007_ESP32S3 compile error

matwan77, 2025-01-30:
Dear Sam,

I'm trying to compile the sketch using IDE 2.3.4 for ESP32-S3 Feather but during this operation receiving information as below:

"Sketch uses 1604948 bytes (111%) of program storage space. Maximum is 1441792 bytes.
Global variables use 94116 bytes (28%) of dynamic memory, leaving 233564 bytes for local variables. Maximum is 327680 bytes.
Sketch too big; see https://support.arduino.cc/hc/en-us/articles/360013825179 for tips on reducing it.
text section exceeds available space in board
Compilation error: text section exceeds available space in board"

PLease, could you help me to understand what i do wrong?
Thank you in advance.
Mateusz

matwan77, 2025-01-30:
Thank you Sam!
It works, now need tu study everything, including how to operate menu, because clicking button only 2 diodes are changed :)
Thank you one more time for your amazing work!
With best regards.
Mateusz
thrak10@gmail.com

electricityforprogress, 2025-01-30:
Very glad to hear that it worked! Yeah you know the menu mode and button
with knob don't really work for most users, I don't understand why because
it's the production code that I've used in my devices. My suggestion is to
ignore the button and menus, make any nitty or other configuration settings
in the code base itself, and just use the knob to control the threshold.
Although I have to admit it is fun to be able to change the scaling
algorithm on the fly.

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

st80356, 2025-04-09:
Hello and thank you @electricityforprogress.  I'm having a lot of trouble getting the correct library versions to compile in the Arduino IDE 1.8.1 and 2.3.4.

Could you please upload a .bin of the latest version so I can flash it directly with and ESP flasher, or provide some hints on the correct library releases that will allow it to upload with a specific version of the Arduino IDE?

Thank you again for a really cool project!

electricityforprogress, 2025-04-11:
@st80356 yes compiling is a pain, and changes to the espressif IDE breaks code (sadly).  But there is a bin in the folder  https://github.com/electricityforprogress/BiodataFeather/blob/master/Biodata_v007_ESP32S3/Biodata_Feather_ESP32_07.ino.adafruit_feather_esp32s3.bin

st80356, 2025-04-11:
Thank you for the insight and reply!

I tried that .bin file too but I'm getting no signs of life from my
boards.

Need to look at the components to troubleshoot then.

Just one last question, which version of the Arduino IDE did you use to
compile the newest .ino?

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

electricityforprogress, 2025-04-11:
The .bin file is very old, back from when I posed the code, I don't know the versions.  There are many many ESP32 boards, this will only work with the ESP32-S3 variety.  If you have a normal ESP32 you can try the 005 version of the code.

st80356, 2025-04-11:
Thanks so much for your time; I'll give them a try!

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

Closed 2025-04-11.

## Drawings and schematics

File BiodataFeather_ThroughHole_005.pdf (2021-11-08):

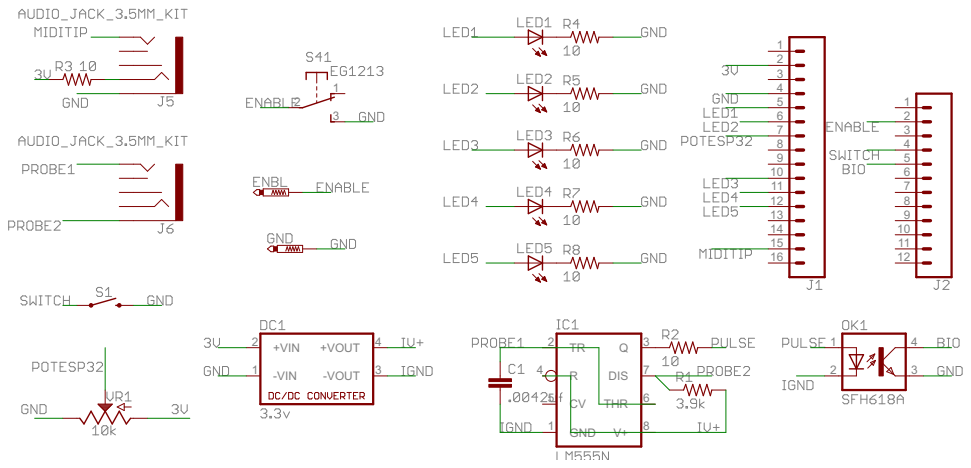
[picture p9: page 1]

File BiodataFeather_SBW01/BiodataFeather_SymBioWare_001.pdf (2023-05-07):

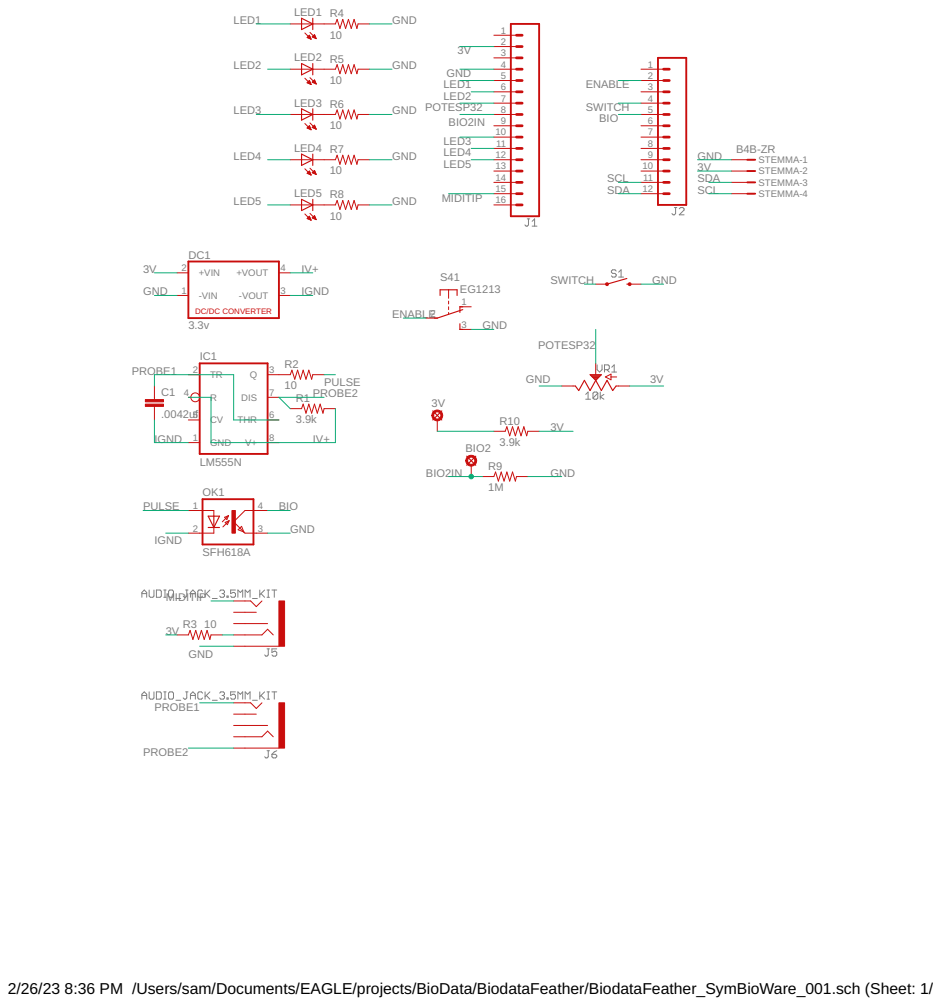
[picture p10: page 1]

STEMMA-1 STEMMA-2 STEMMA-3 STEMMA-4

2/26/23 8:36 PM /Users/sam/Documents/EAGLE/projects/BioData/BiodataFeather/BiodataFeather_SymBioWare_001.sch (Sheet: 1/1)

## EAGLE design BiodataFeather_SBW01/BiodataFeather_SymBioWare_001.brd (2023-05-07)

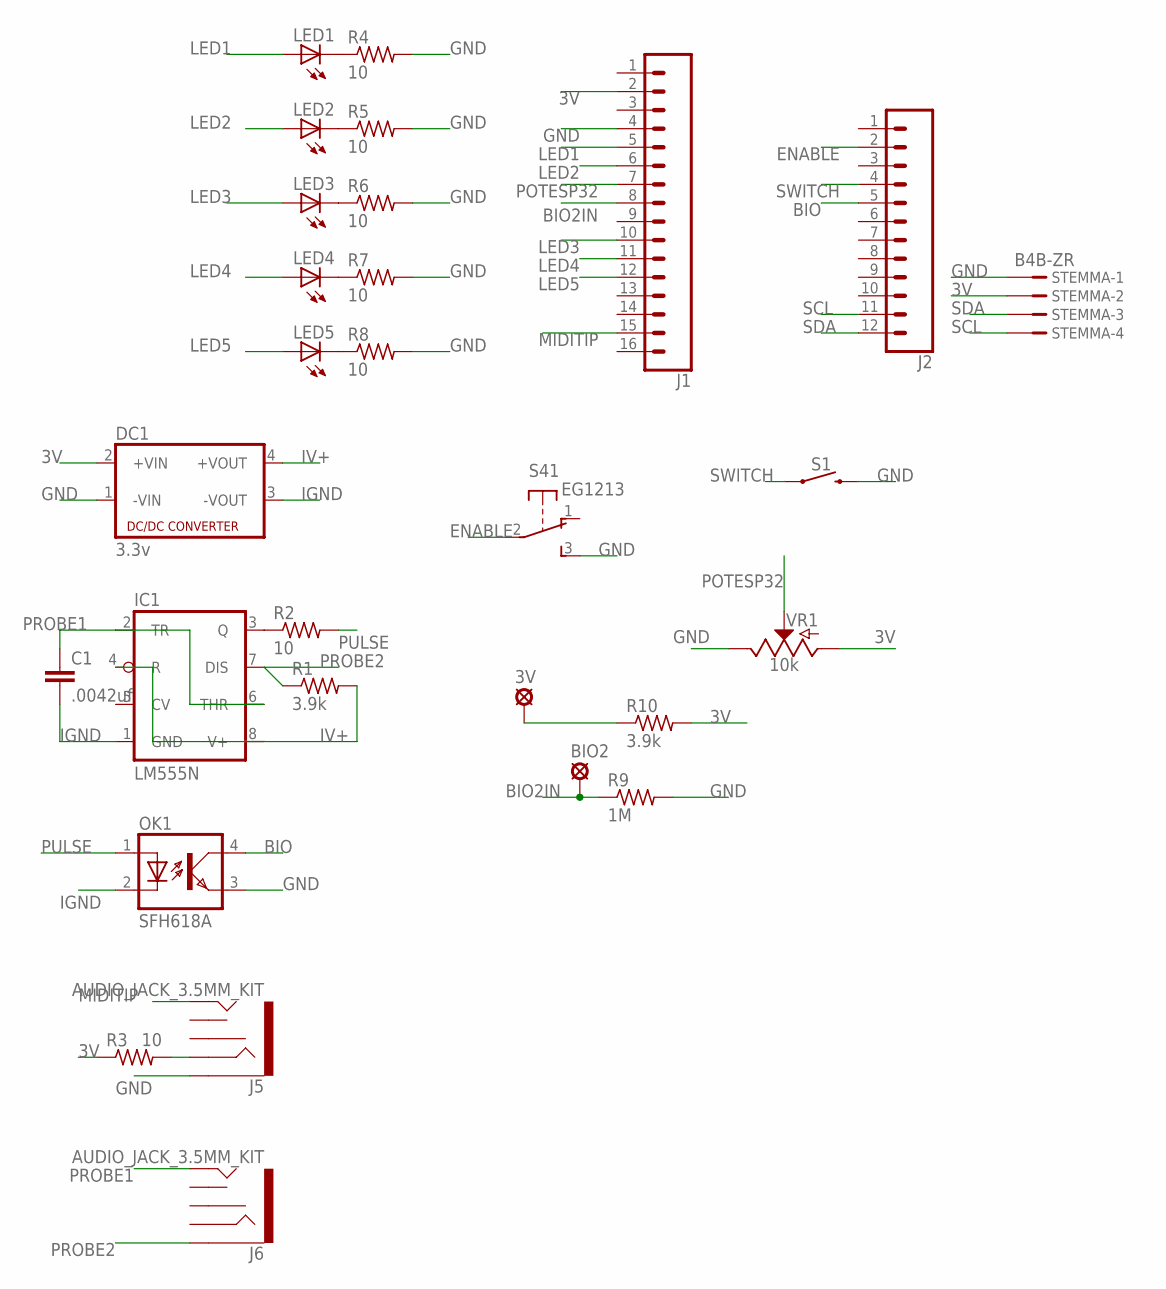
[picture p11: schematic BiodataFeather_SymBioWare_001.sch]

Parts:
3V: SE14
BIO2: SE14
C1: .0042uf; C2.5-2
DC1: 3.3v; NME
IC1: LM555N; DIL08
J1: CONN_161X16_NO_SILK; 1X16_NO_SILK
J2: CONN_12NO_SILK; 1X12_NO_SILK
J5, J6: AUDIO_JACK_3.5MM_KIT; AUDIO-JACK-KIT
LED1, LED2, LED3, LED4, LED5: LED5MM
OK1: SFH618A; DIP4
R1, R10: 3.9k; 0204V
R2, R3, R4, R5, R6, R7, R8: 10; 0204V
R9: 1M; 0204V
S1: MOMENTARY-SWITCH-SPST-PTH-6.0MM; TACTILE_SWITCH_PTH_6.0MM
S4: EG1213
STEMMA: B4B-ZR
VR1: 10k; POT-PTH-ALPS-KIT

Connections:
3V: DC1.2 (+VIN), J1.2, R3.1, R10.2, STEMMA.2, VR1.P$3 (A)
BIO: J2.5, OK1.4 (COL)
BIO2IN: BIO2.MP, J1.8, R9.1
ENABLE: J2.2, S4.2
GND: DC1.1 (-VIN), J1.4, J5.SLEEVE, OK1.3 (EMIT), R4.2, R5.2, R6.2, R7.2, R8.2, R9.2, S1.3 (2), S4.3 (S), STEMMA.1, VR1.P$1 (E)
IGND: C1.2, DC1.3 (-VOUT), IC1.1 (GND), OK1.2 (C)
IV+: DC1.4 (+VOUT), IC1.4 (R), IC1.8 (V+), R1.2
LED1: J1.5, LED1.A
LED2: J1.6, LED2.A
LED3: J1.10, LED3.A
LED4: J1.11, LED4.A
LED5: J1.12, LED5.A
MIDITIP: J1.15, J5.TIP
unnamed: IC1.3 (Q), R2.1
unnamed: J5.RING, R3.2
unnamed: LED1.K (C), R4.1
unnamed: 3V.MP, R10.1
unnamed: LED2.K (C), R5.1
unnamed: LED3.K (C), R6.1
unnamed: LED4.K (C), R7.1
unnamed: LED5.K (C), R8.1
POTESP32: J1.7, VR1.P$2 (S)
PROBE1: C1.1, IC1.2 (TR), IC1.6 (THR), J6.TIP
PROBE2: IC1.7 (DIS), J6.SLEEVE, R1.1
PULSE: OK1.1 (A), R2.2
SCL: J2.11, STEMMA.4
SDA: J2.12, STEMMA.3
SWITCH: J2.4, S1.1

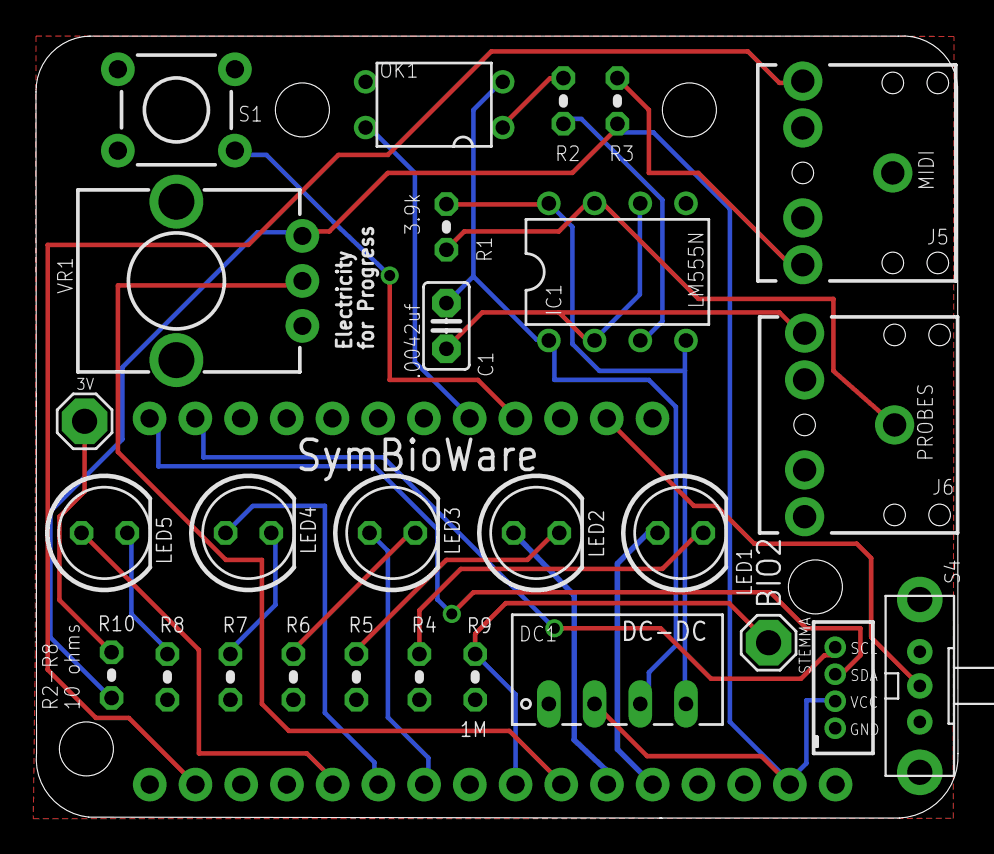
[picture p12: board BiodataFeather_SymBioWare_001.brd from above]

Board: 2 copper layers, 51.2 x 43.4 mm, 29 parts (0 on the bottom side), 28 nets.

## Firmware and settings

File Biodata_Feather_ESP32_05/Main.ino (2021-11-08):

// -----------------------------------------------------------------------------
//
// -----------------------------------------------------------------------------
void setup() {

  if (debugSerial) Serial.begin(115200); // Serial for debugging
  
      //load from EEPROM memory
  EEPROM.begin(EEPROM_SIZE);
  
  //pinMode(buttonPin, INPUT_PULLUP); //button managed by PinButton
  pinMode(interruptPin, INPUT_PULLUP); //pulse input

     //welcome message
    if(debugSerial) Serial.println(); Serial.println();
    if (debugSerial) Serial.println(F("Welcome to Biodata Sonification .. now with BLE and Wifi!"));

//check if button is held at startup, potentially for reset stuff
 

    //LED light show
    //ledcSetup(0,5000,13);
    for(byte i=0;i<5;i++) {
        ledFaders[i].Setup(i);
        ledFaders[i].Set(ledFaders[i].maxBright,500*(i+1)); 
    }
    unsigned long prevMillis = millis();
    while(prevMillis+1000>millis()) {
        for(byte i=0;i<5;i++) ledFaders[i].Update();
    }
    for(byte i=0;i<5;i++) {
        ledFaders[i].Set(0,500*(i+1)); 
    }
    prevMillis = millis();
    while(prevMillis+3000>millis()) {
        for(byte i=0;i<5;i++) ledFaders[i].Update();
    }
   

 if(!digitalRead(buttonPin)) {
     if (debugSerial) Serial.println("Button Held at Bootup!");
     ledFaders[4].Set(255, 1000);
     ledFaders[4].Update();
     while(ledFaders[4].isRunning) {
        ledFaders[4].Update();
     }
     //reset memory - chromatic scale, channel 1, wifi off, ble on
      EEPROM.write(0, 0); EEPROM.write(1, channel); EEPROM.write(2,0); EEPROM.write(3,1);
      EEPROM.commit();
         bleMIDI = 1;
         wifiMIDI = 0;
         //channel = 1;  //declared at top
         scaleSelect = scaleChrom;

     ledFaders[4].Set(0, 0); //does this set immediately?

  }

//read from memory and load
  byte scaleIndex = EEPROM.read(0);
  byte midiChannel = EEPROM.read(1);
  byte wifiPower = EEPROM.read(2);
  byte blePower = EEPROM.read(3);
  byte keybyte = EEPROM.read(4);
  if(keybyte != 1) { //if not initialized first time - Scale,channel,wifi,bluetooth, key
    //init for millersville
    //EEPROM.write(0, 0); EEPROM.write(1, 1); EEPROM.write(2,1); EEPROM.write(3,0); EEPROM.write(4,1);
     //normal init - ble ON, wifi OFF
      EEPROM.write(0, 0); EEPROM.write(1, channel); EEPROM.write(2,0); EEPROM.write(3,1); EEPROM.write(4,1);
      EEPROM.commit();
      Serial.println("EEPROM Initialized - First time! BLE ON, WiFi OFF");
         scaleIndex = EEPROM.read(0);
         midiChannel = EEPROM.read(1);
         wifiPower = EEPROM.read(2);
         blePower = EEPROM.read(3);
  }
  
  channel = midiChannel; //need two bytes to hold up to 16 channels!!
  
                       if(scaleIndex == 0) scaleSelect = scaleChrom; 
                       if(scaleIndex == 1) scaleSelect = scaleMinor; 
                       if(scaleIndex == 2) scaleSelect = scaleDiaMinor; 
                       if(scaleIndex == 3) scaleSelect = scaleMajor; 
                       if(scaleIndex == 4) scaleSelect = scaleIndian; 
  wifiMIDI = wifiPower;
  bleMIDI = blePower;
  

  if (serialMIDI)  setupSerialMIDI(); // MIDI hardware serial output
  if (wifiMIDI)    setupWifi(); 
  else { WiFi.disconnect(true); delay(1);   WiFi.mode(WIFI_OFF); delay(1);} //turn wifi radio off
  if (bleMIDI)     bleSetup();

  //setup pulse input pin
  attachInterrupt(interruptPin, sample, RISING);  //begin sampling from interrupt

  for(byte i=0;i<5;i++) { ledFaders[i].Update(); ledFaders[i].Set(0,2000); } //all fade off

} //end setup(){}

// -----------------------------------------------------------------------------
//
// -----------------------------------------------------------------------------
void loop() {
  //manage time
  currentMillis = millis();
  MIDI.read();
  
  //analyze data when the buffer is full
  if (sampleIndex >= samplesize)  {
    analyzeSample();
  }

  // Manage MIDI
  checkNote();  //turn off expired notes
  checkControl();  //update control value

  // Mange LEDs
  for(byte i=0;i<5;i++) ledFaders[i].Update();
  
  //Manage pot and button
   checkKnob();  // updates threshold in main biodata mode
 

//this keeps the Red LED on when wifi is not connected
  if(wifiMIDI && WiFi.status() != WL_CONNECTED) { ledFaders[0].Set(ledFaders[0].maxBright,0); } 
  
  button.update();

  if(button.isSingleClick()) {
       if (debugSerial) {
        Serial.println("---***---***---***---***---***---***");
          byte mac[6];
          WiFi.macAddress(mac);
          String macAddr =  String(mac[0],HEX) +String(mac[1],HEX) +String(mac[2],HEX) +String(mac[3],HEX) + String(mac[4],HEX) + String(mac[5],HEX);          
          int uniq =  mac[0] + mac[1] + mac[2] + mac[3] + mac[4] + mac[5];
          Serial.print("Biodata "); Serial.println(uniq);
          Serial.print("MIDI Channel "); Serial.println(channel);
          Serial.print("ScaleIndex "); Serial.println(EEPROM.read(0));
          Serial.print("Threshold "); Serial.println(threshold);
          Serial.print("MAC Address: "); Serial.println(macAddr);
          
          //bluetooth status
          if(bleMIDI) {
              Serial.print("Bluetooth On "); 
              if(deviceConnected)  Serial.println("Bluetooth Connected"); else Serial.println("Bluetooth DisConnected");
          } else Serial.println("Bluetooth Off");


        if(wifiMIDI){
              //wifi connection status
          Serial.print(ssid); Serial.print(F("  pass: ")); Serial.print(pass); Serial.println();
          if(WiFi.status() == WL_CONNECTED) {
            Serial.println("Wifi Connected");
          } else Serial.println("WiFi Not Connected");

       //wifi Signal level
          Serial.print("RSS Signal level: "); Serial.println(WiFi.RSSI());
          if(isConnected) Serial.println(F("RTP MIDI Connected!"));
          else Serial.println("RTP MIDI Not Connected");
            Serial.println();
            Serial.print(F("IP address is "));
            Serial.println(WiFi.localIP());
        } else Serial.println("Wifi Off");
      
      }

              //battery monitor
        float batteryLevel = float(analogRead(35))/float(4095)*2.0*3.3*1.1; //A13
        Serial.print("Battery Voltage: ");
        Serial.println(batteryLevel); //of course while plugged into usb the voltage will be 4.x


        int knobValue = analogRead(potPin);
        int prevKnob = knobValue;
        unsigned long menuTimer = millis();
        int menu = 0; //main biodata play mode
        while(menuTimer + 10000 > millis()) {
           //knob turn to extend time and select menu
           knobValue = analogRead(potPin);
          // if(abs(knobValue - prevKnob) > 45){
            //select range for each menu and check for click
             menu = map(knobValue, 0, 4095, 0, 4);

            for(byte i=0;i<5;i++) { ledFaders[i].Set(0,0); } //turn leds off
            //turn on Menu LED
               //blink led during selection
               if((blinkTime ) < millis()) { blinkToggle = !blinkToggle; blinkTime = millis(); }   
               if(blinkToggle) ledFaders[menu].Set(ledFaders[menu].maxBright,0);
                        
            //reset timer
            //menuTimer = millis();
          // }  if knob change
           prevKnob = knobValue;
           
           //check for click and enter Menu mode
             button.update();
             int modeValue = 0;
             if(button.isSingleClick()) {
                Serial.print("Menu "); Serial.println(menu);
                menuTimer = millis();
                while(menuTimer + 20000 > millis()){
                    
                    button.update();
                    //knob turn to extend time and select menu
                    knobValue = analogRead(potPin);
                   // if(abs(knobValue - prevKnob) > 45){  //if knob change
                      //menuTimer = millis();
                     //turn on Value LED, perhaps pulse?
                      for(byte i=0;i<5;i++) { ledFaders[i].Set(0,0); } //all off
 
                     //select range for each menu and check for click
                     
                      if(menu == 0) { // MIDI Scaling
                       modeValue = map(knobValue, 0, 4095, 0, 4);
                       //blink led during selection
                       if((blinkTime + 150) < millis()) { blinkToggle = !blinkToggle; blinkTime = millis(); }   
                       if(blinkToggle) ledFaders[modeValue].Set(ledFaders[modeValue].maxBright,0);
                       if(menu!=modeValue) ledFaders[menu].Set(ledFaders[menu].maxBright,0); //red0
                       
                       if(modeValue == 0) scaleSelect = scaleChrom; 
                       if(modeValue == 1) scaleSelect = scaleMinor; 
                       if(modeValue == 2) scaleSelect = scaleDiaMinor; 
                       if(modeValue == 3) scaleSelect = scaleMajor; 
                       if(modeValue == 4) scaleSelect = scaleIndian; 
                       
                      }
                      if(menu==1) { //MIDI Channel Selection
                        modeValue = map(knobValue, 0, 4095, 1, 17); if(modeValue == 17) modeValue = 16;
                        //if((blinkTime + 150) < millis()) { blinkToggle = !blinkToggle; blinkTime = millis(); }   
                        //if(blinkToggle) ledFaders[modeValue].Set(ledFaders[modeValue].maxBright,0); 
                        //display channel in binary
                         int showChannel = modeValue;
                         for (byte i = 0; i < 5; i++) ledFaders[i].Set(0,0); //turn off
                          //convert to binary
                          int cursorPos = 0;
                          int binaryValue[5];
                          for(int i=0;i<5;i++){
                            binaryValue[i] = showChannel % 2;
                            showChannel = showChannel/2;
                          }
                         
                         for (byte i = 0; i < 5; i++) {
                            //if this bit should be on then turn it on...
                             if(binaryValue[i]) ledFaders[i].Set(ledFaders[i].maxBright, 0);
                         }
                       
                      }
                      if(menu==2) { //Wifi Config
                          //display green LED for wifi mode, red if wifi off, yellow if wifi not conn, white if RTP connected
                          //turn knob to select (flashing) - Wifi Off - Red; Wifi On - White
                          
                          //knob map to 0/1
                         modeValue = map(knobValue, 0, 4095, 0, 1);
                          //blink led during selection
                         if((blinkTime + 150) < millis()) { blinkToggle = !blinkToggle; blinkTime = millis(); }   
                         if(blinkToggle) ledFaders[modeValue*4].Set(ledFaders[modeValue].maxBright,0);
                         ledFaders[menu].Set(ledFaders[menu].maxBright,0); //green


                      }                      
                      if(menu==3) { //Bluetooth Config
                        //display blue for ble mode, if discon
                        modeValue = map(knobValue, 0, 4095, 0, 1);
                        if((blinkTime + 150) < millis()) { blinkToggle = !blinkToggle; blinkTime = millis(); }   
                        if(blinkToggle) ledFaders[modeValue*4].Set(ledFaders[modeValue].maxBright,0);
                        ledFaders[menu].Set(ledFaders[menu].maxBright,0); //blue
                        
                        
                      }
                      if(menu==4) {
                          int batt = batteryLevel*10; 
                          modeValue = map(batt, 32,44,0,4);
                        if((blinkTime + 150) < millis()) { blinkToggle = !blinkToggle; blinkTime = millis(); }   
                        if(blinkToggle) ledFaders[modeValue].Set(ledFaders[modeValue].maxBright,0);
                        if(modeValue != menu) ledFaders[menu].Set(ledFaders[menu].maxBright,0); //white
                        
                      } 
                            
                      if(button.isSingleClick()) { ///select value sub menu
                        //light show fast flash
                        for(byte i=0;i<5;i++) { ledFaders[i].Set(0,0); } //all off
                        ledFaders[menu].Set(ledFaders[menu].maxBright,0);
                        delay(75);
                        ledFaders[menu].Set(0,0);
                        delay(75);
                        ledFaders[menu].Set(ledFaders[menu].maxBright,0);
                        delay(75);
                        ledFaders[menu].Set(0,0);
                        delay(75);
                        ledFaders[menu].Set(ledFaders[menu].maxBright,0);
                        delay(75);
                        ledFaders[menu].Set(0,0);
                        
                        for(byte i=0;i<5;i++) { ledFaders[i].Set(0,0); } //all off

                        if(menu == 0){
                          EEPROM.write(0,modeValue);
                         // EEPROM.commit();
                          Serial.print("MIDI Scale "); Serial.println(modeValue);
                        }
                        if(menu == 1){
                          channel = modeValue;  //set channel value
                          EEPROM.write(1,channel);
                        //  EEPROM.commit();
                          Serial.print("Channel "); Serial.println(channel);
                        }
                        //save and set values as needed (wifi/bluetooth)
                        if(menu == 2){
                             if(modeValue == 0 && wifiMIDI == 1)   { 
                                if(debugSerial) Serial.println("Wifi Shutdown ");
                                WiFi.disconnect(true); delay(1); 
                                WiFi.mode(WIFI_OFF); delay(1);
                               // if(debugSerial) Serial.println(WiFi.status() == WL_CONNECTED)
                                  wifiMIDI = 0;
                                  EEPROM.write(2,0);
                             } //turn off wifi and power down (disconnect, turn off, )
                             if(modeValue == 1)  { 
                                wifiMIDI = 1; 
                                EEPROM.write(2,1);
                                setupWifi();  //turn on wifi and initialize (turn on, connect)
                             }   
                        }
                        if(menu == 3) {
                              if(modeValue == 0)  { bleMIDI = 0; btStop(); EEPROM.write(3,0); Serial.println("BLE Off");}//turn off bluetooth
                              if(modeValue == 1)  { bleMIDI = 1;  btStart(); bleSetup(); EEPROM.write(3,1); Serial.println("BLE On");}//turn on bluetooth
                              ledFaders[menu].Set(0,700); //turn off Blue led
                        }
//                        if(menu == 4) { //display wifi signal level
//                          for(byte i=0;i<5;i++) { ledFaders[i].Set(0,0); } //all off
//                          byte wifiLevel = map(abs(WiFi.RSSI()),90,30,0,4);
//                          for(byte j=0;j<wifiLevel;j++){
//                            ledFaders[j].Set(ledFaders[j].maxBright,0);
//                          }
//                          delay(3000);
//                          for(byte i=0;i<5;i++) { ledFaders[i].Set(0,700); } //all off
////                          if(button.isSingleClick()) { 
//                          Serial.print("RSSI "); Serial.print(WiFi.RSSI()); 
//                          Serial.print(" wifiLevel "); Serial.println(wifiLevel);
////                          return;
////                          }
//                        }
                        
                        EEPROM.commit(); //save all the values!!

                        return; //break; //save here              
                      }
                    //}  //if knob change
                      //unsure if button clicks get here...
                   if(button.isSingleClick()) {
                     for(byte i=0;i<5;i++) { ledFaders[i].Set(0,0); } //all off
                     Serial.println("shouldnt get here in menus?");
                     return; //save here
                   }
                   prevKnob = knobValue;
              
                }
                
             } 
          
        }
        
        for(byte i=0;i<5;i++) { ledFaders[i].Set(0,0); } //all off


        
          
  }
  //if double, if long click, etc
  
  



} //end loop(){}

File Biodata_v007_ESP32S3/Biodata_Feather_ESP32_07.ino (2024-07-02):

 //   ESP32 S3 
//Electricity for Progress
// electricityforprogress.com
// store - Biodata - Modules - Custom
// **-----------------------------------------------------------------------------
//ESP32-S3 UDP/RTP AppleMIDI over wifi
//Biodata Sonification pulse input data via interrupt
//Knob and button interface
//LEDs using PWM fading
//ESP32 Feather A13 pin re ads half of battery voltage (4.2 (3.7) -3.2V)
// ~~~NEW~~~
//  * Captive Portal for wifi configuration
//  * Velocity - five levels of control: red-100,yellow-accent(90/120),
//     green-(75,95,120),blue-musical map(value,x,y,50,120),
//     white-fluent map(value,x,y,0,127)
// **-----------------------------------------------------------------------------

/***
1. Static IP Addressing
2. -removed-
3. LED display of wifi status, RTP status, battery status?
  Green Wifi Connected, White RTP connected, Yellow RTP disc conn, Blue Ble conn
  menus
    Red - MIDI channel, Yellow - MIDI Scale, Green - WiFi on/off, Blue - Ble on/off, White - Battery level
4. Move key variables to top of .ino (channel, wifi cred, IP, blue/wifi mode)
5. Velocity using CC80, mapping velocity range
6. Enable CC, variable for cc number and mapping range
7. press button, display status LED and usb serial information print

***/
// Wifi Credentials ~~~~~~~~~~~!!!!

char ssid[] = "OxfordEast"; //  your network SSID (name)
char pass[] = "oxfordeast";    // your network password (use for WPA, or use as key for WEP)
// ~~~~~~~~~~~~~!!!!
//  Set the MIDI Channel of this node
  byte channel = 1; // 
  IPAddress local_IP(192,168,68,207); //use this IP
  bool staticIP = false;  // true;  //toggle for dynamic IP
//static IP  

//MIDI Note and Controls
const byte polyphony = 5; // 1; //mono  // number of notes to track at a given time

//******************************
//set scaled values, sorted array, first element scale length
//the whole scaling algorithm needs to be refactored ;)
//int scaleDiaMinor[]  = {7, 0, 2, 3, 5, 7, 8, 10};
int scalePenta[]  = {5, 0, 3, 5, 7, 9};
int scaleMajor[]  = {7, 0, 2, 4, 5, 7, 9, 11};
int scaleIndian[]  = {7, 0, 1, 1, 4, 5, 8, 10};
int scaleMinor[]  = {7, 0, 2, 3, 5, 7, 8, 10};
int scaleChrom[] = {13, 0, 1, 2, 3, 4, 5, 6, 7, 8, 9, 10, 11, 12};
     //enter the scale name here to use
int *scaleSelect = scaleChrom; //initialize scaling
byte defScale = 3; 

int root = 0; //initialize for root
//*******************************

//Debug and MIDI output Settings ********
byte debugSerial = 1; //debugging serial messages
byte rawSerial = 0; // raw biodata stream via serial data
byte serialMIDI = 1; //write serial data to MIDI hardware output
byte wifiMIDI = 0; //do all the fancy wifi stuff and RTP MIDI over AppleMIDI
byte bleMIDI = 1; //bluetooth midi
byte usbmidi = 1; //usb MIDI connection <Adafruit_TinyUSB.h> for ESP32S3
byte midiMode = 0;  //change mode for serial, ble, wifi, usb
byte wifiActive = 0; //turn the wifi on and off, needed for wifiMIDI apparently
byte bleActive = 0; //toggle for connected disconnected?  prob not needed, use library
byte midiControl = channel; // 1; //use channel 16 to recieve parameter changes? fancy! or recv on base channel...hmm
//setting channel to 11 or 12 often helps simply computer midi routing setups
int noteMin = 36; //C2  - keyboard note minimum
int noteMax = 96; //C7  - keyboard note maximum
byte controlNumber = 80; //set to mappable control, low values may interfere with other soft synth controls!!
unsigned long rawSerialTime = 0;
int rawSerialDelay = 0;
// **************************************

#include <EEPROM.h>
#define EEPROM_SIZE 5 // scaleindex, midi channel, wifi, bluetooth, key


// I/O Pin declarations
int buttonPin = 13;
int potPin = A2; //A2 ESP32 and A0 ESP8266
const byte interruptPin = 12; //galvanometer input

//leds
byte leds[5] = {18,17,8,36,35}; //ESP32-S3 pins  // ESP32Huzzah -- { 26,25,4,5,18 };
byte ledBrightness[5] = {50,110,120,120,60};  //{185,255,255,255,195};  
byte maxBrightness = 60;
bool blinkToggle = 0;
unsigned long blinkTime = 0; 

//USB MIDI
#include <Adafruit_TinyUSB.h>
#include <MIDI.h>
Adafruit_USBD_MIDI usb_midi;
MIDI_CREATE_INSTANCE(Adafruit_USBD_MIDI, usb_midi, usbMIDI);


//Bluetooth Configuration
#include <BLEDevice.h>
#include <BLEUtils.h>
#include <BLEServer.h>
#include <BLE2902.h>

#define SERVICE_UUID        "03b80e5a-ede8-4b33-a751-6ce34ec4c700"
#define CHARACTERISTIC_UUID "7772e5db-3868-4112-a1a9-f2669d106bf3"

BLECharacteristic *pCharacteristic;
bool deviceConnected = false;

uint8_t midiPacket[] = {
   0x80,  // header
   0x80,  // timestamp, not implemented 
   0x00,  // status
   0x3c,  // 0x3c == 60 == middle c
   0x00   // velocity
};

class MyServerCallbacks: public BLEServerCallbacks {
    void onConnect(BLEServer* pServer) {
      deviceConnected = true;
    };

    void onDisconnect(BLEServer* pServer) {
      deviceConnected = false;
    }
};
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

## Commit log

2020-08-18 Initial upload
    [BiodataFeatherProMicro_004.brd, BiodataFeatherProMicro_004.sch]
2020-08-18 Added BOM
2020-09-06 Added gerbers for Dmitriy
    These gerbers are untested ;) until my NextPCB order goes out!
2021-01-13 latest biodata wifi update
    version for Darren including blue/purple light show during wifi connection and some elements for future battery level display.
2021-11-08 Menu updates and reset
    modifications to the hard reset feature, hold button during boot light show and the white LED will flash indicating restore from EEPROM. On 'first upload' from a fresh ESP32 the EEPROM needs to be set and read.
    [Biodata_Feather_ESP32_05.ino, Main.ino]
2021-11-08 schematic
    PDF export of biodata feather schematic
2022-01-17 Enclosure
    enclosure stls, plus 'shortie' for no header builds.
    [BiodataButtons_001.stl, BiodataDiffuser_001.stl, BiodataShortie_top_001.stl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]
2022-03-12 comment out DBG
    commented out DBG macro print statements from AppleMIDI example code
2022-08-05 ESP32S3 with USB MIDI
    This includes USB MIDI output for an Adafruit ESP32 S3
2023-05-07 Updated version with STEMMA i2C
    [BiodataFeather_SymBioWare_001.brd, BiodataFeather_SymBioWare_001.sch]
2024-04-02 BOM
    Digikey BOM for ESP32-S3 Biodata Sonification kit, including Breadboard ;)
    [Biodata Feather BOM.xlsx]
2024-06-24 Update Biodata_Feather_ESP32_07.ino
    updates for ledc due to espressif BREAKING changes in v3.0
2024-07-02 Update Biodata_Feather_ESP32_07.ino
    updated for ledc issues
    [Biodata_Feather_ESP32_07.ino]

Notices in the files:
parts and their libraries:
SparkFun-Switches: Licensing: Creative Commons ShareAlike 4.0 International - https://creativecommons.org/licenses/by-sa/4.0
